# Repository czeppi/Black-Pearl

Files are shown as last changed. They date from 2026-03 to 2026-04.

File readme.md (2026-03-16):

# Black Pearl

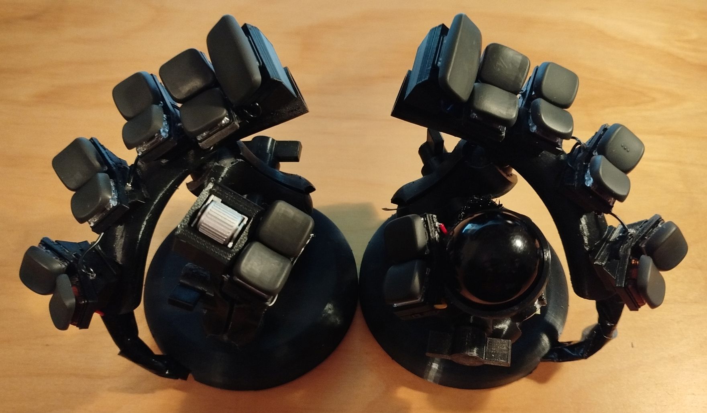
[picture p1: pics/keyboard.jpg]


**An extrem ergonomic keyboard with integrated trackball and roller encoder**

# Quick links

- [build case](case/readme.md)
- [build key caps](caps/readme.md)
- [firmware](firmware/readme.md)

# Features

- min. necessary finger movement
- using QWERTY/QWERTZ
- max. ergonomic
- only 22 keys
- integrated trackball + roller encoder
- hot-swapable
- easy to adjust
- slightly modified KLP key caps
- own firmware (based on Adafruit Circuit Python)
- diodeless
- using Raspberry Pico
- handwired

## using chords for 3rd row

The finger movement should reduced as much as possible.
Every finger was assigned two keys.
Pressing both keys simulates a middle row => a QWERTZ layout is possible.

The Index finger gets 3 physical keys, which can simulate 6 virtual keys.

With the terrific KLP keycaps it is much easier to press both keys blind.

# BOM (Bill of Material)

- 2 raspberry pi Pico (I'm using the Pico 2W, but the Pico 1 should also work)
- 1 PMW3389 trackball sensor
- 3 trackball bearings (s. https://kbd.news/Trackball-bearing-comparison-1757.html, I'm using BTUs of steel)
- 1 EVQWGD001 roller sensor (no longer available, so https://github.com/Taro-Hayashi/THQWGD001 could be a replacement perhaps)
- 2 100mm metal disc (2mm thickness - or more) for the feet
- 22 kailh hot swap sockets
- 22 kailh Choc V1 keys
- lots of 2mm flat hat screws
- lots of 2.5mm flat hat screws
- lots of 3mm 
- lots of heat inserter sets
- lots of cables (I'm using AWG 26 with solid core, but this is a matter of personal preference)

# A look inside

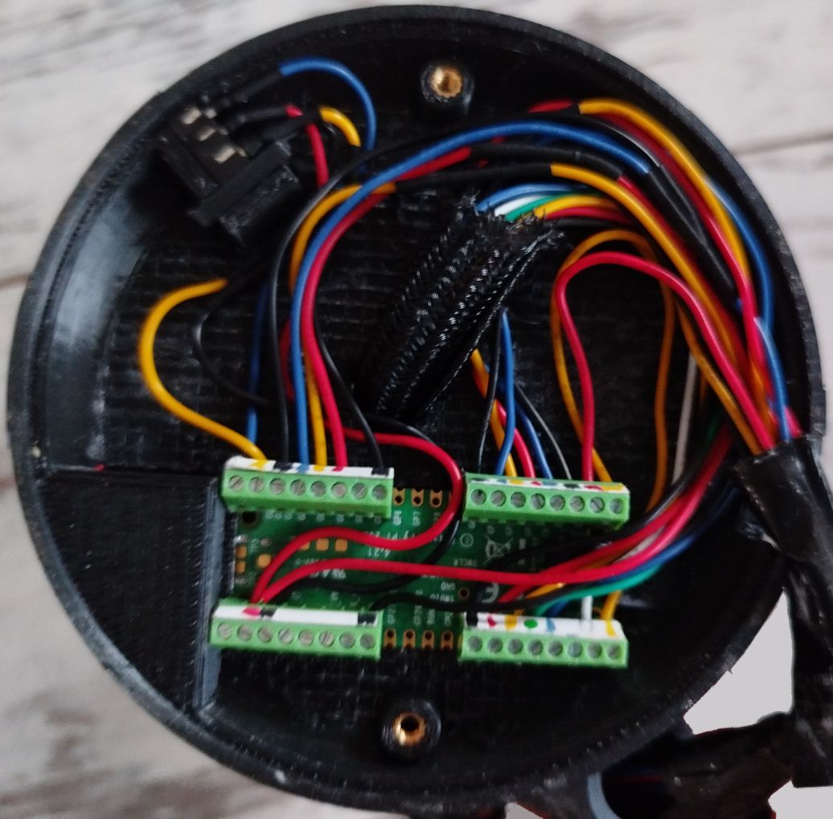
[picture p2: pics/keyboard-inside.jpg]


# Why yet another keyboard?

I'm using a piantor keyboard since over a year and I'm quite happy with it.
The main issue is the lack of a track ball, so I switch beetween keyboard and mouse permantly.
A 2nd disadvantage are the thumb-clusters, which are not very ergonomic.

I'm print the case of a charibdis keyboard, but the distances between the keys are too far for me.

# Some notes to the name

The name relationship to the ship in "Pirates of the Caribbean" is no coincidence.
Cause both has some attributes in common:
- black (that much is certain - with the words of captain Sparrow)
- extraordinary
- fast (hopefully)

...and, every switch pair holder has some similarities to a historical ship

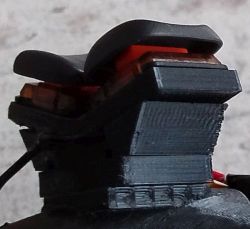
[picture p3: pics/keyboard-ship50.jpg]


# Related keyboards

- Charybdis (a famous keyboard with trackball)
- Dactyl Manuform Skeleton (has a similar exotic design)
- Gull + Heron from Sneftel
- Proto2 + Heavily Modified Gigi (using chords for 3rd row too)

# Licence

- case: CC-BY-SA
- keycaps: CC-BY-SA
- firmware: GPL V3

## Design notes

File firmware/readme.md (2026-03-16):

# Firmware

## Why an own firmware

It is very difficult to simulate a 3rd row with the existing keyboard firmwares like QMK or KMK.
Since I am a professional software developer, I decided to write my own. 
I thought that this should be a small piece of work, cause only a subset of the typically firmware is needed (no matrix for example) - that was an error!
All in all it take over three weeks of work.

## Install

### download circuitpython

you can use a pico or a pico2

pico: https://circuitpython.org/board/raspberry_pi_pico_w/
=> adafruit-circuitpython-raspberry_pi_pico_w-en_US-9.2.9.uf2

pico2: https://circuitpython.org/board/raspberry_pi_pico2_w/ 
=> adafruit-circuitpython-raspberry_pi_pico2_w-en_US-9.2.9.uf2

### install circuitpython

- connect Pico to USB while Sel-button is pressed => new drive appears
- drag&drop utf2 file to that drive => a new drive appears

### download library bundle

https://circuitpython.org/libraries => adafruit-circuitpython-bundle-9.x-mpy-20250911.zip

### install library bundle

- copy folders adafruit_bus_device + adafruit_hid
- from adafruit-circuitpython-bundle-9.x-mpy-20250911.zip/adafruit-circuitpython-bundle-9.x-mpy-20250911/lib
- to   [CIRCUIT-Python-drive]:/lib

### copy files to left half (connected with computer)

copy this files from this directory to [CIRCUIT-Python-drive]:/

- mainleft.py -> code.py
- base.py
- button.py
- kbdlayoutdata.py
- keyboardcreator.py
- keyboardhalf.py
- keysdata.py
- macrosdata
- reactions.py
- uart.py
- virtualkeyboard.py

### copy files to right half (only connected with left half)

copy this files from this directory to [CIRCUIT-Python-drive]:/

- mainright.py -> code.py
- base.py
- button.py
- kbdlayoutdata.py
- keyboardhalf.py
- keysdata.py
- pmw3389
- uart.py

## Connection info of the PMW3389

### Pins of the PMW3389

| board | | color  | description |
|---|----|---|---|
| RST | RS | brown  | Reset |
| GND | GD | red | Ground |
| MT | MT | orange | Motion (active low interrupt line) |
| SS | SS | yellow | Slave Select / Chip Select |
| SCK | SC | green  | SPI Clock |
| MOSI  | MO | blue | |
| MISO  | MI | purple | |
| VIN | VI | gray | Voltage in up to +5.5V |

### Connection to the Pico

| | | |
|---|---|---|
| SPI0_SCK  | Pin 6 | # SPI0_SCK |
| SPI0_MOSI | Pin 7 | # SPI0_TX  |
| SPI0_MISO | Pin 4 | # SPI0_RX  |
	
| | | |
|---|---|---|
| SPI1_SCK  | Pin 10 | # SPI1_SCK |
| SPI1_MOSI | Pin 11 | # SPI1_TX  |
| SPI1_MISO | Pin 8  | # SPI1_RX  |

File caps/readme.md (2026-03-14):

# Create modified KLP Lame key caps

## Install

### required

- install python (3.12)
- pip install build123d  # 0.10.0

### optional for viewing

- pip install ocp_vscode  # 3.1.2
- install visual studio code  (1.111)
- install OCP CAD Viewer plug in (3.1.2)

the versions in paranthesis or comments are my versions. Newer should work also, but are not tested.

## Start

### with viewing

- open Visual Studio Code
- start one of the main_*.py files

### only creating *.stl files

- start one of the main_*.py files

## Results

- the STL file should be shown in the OCP Viewer
- the STL file should be stored in the caps/#output directory

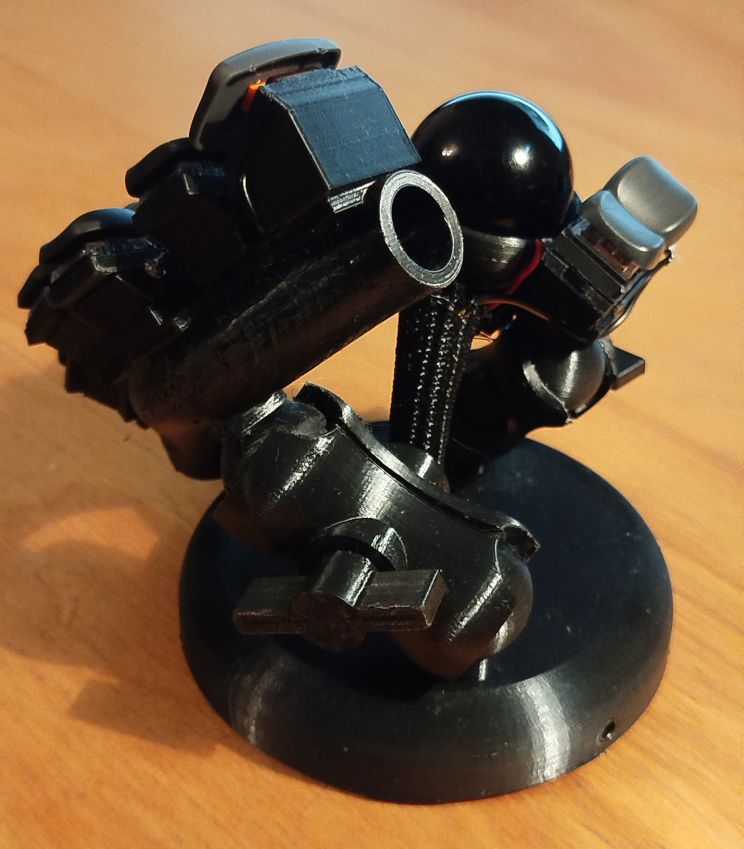
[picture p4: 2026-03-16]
pics/keyboard-right-04.jpg

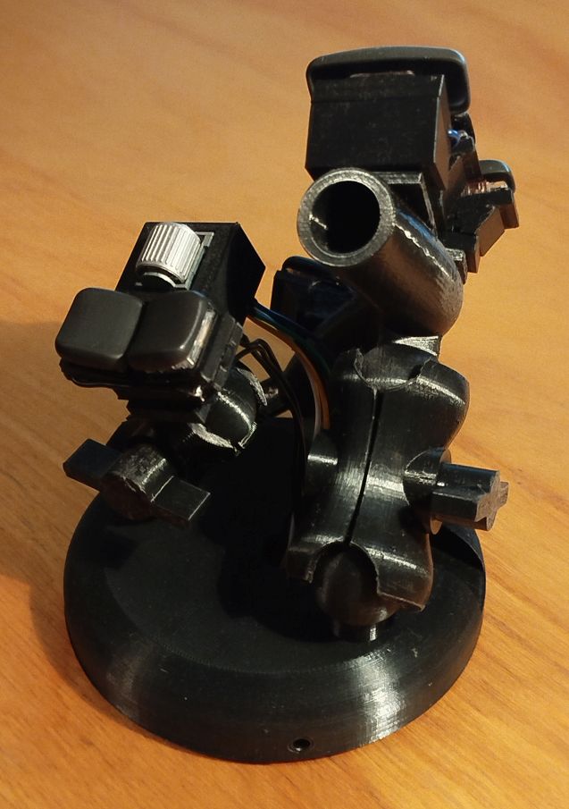
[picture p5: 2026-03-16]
pics/keyboard-left-05.jpg

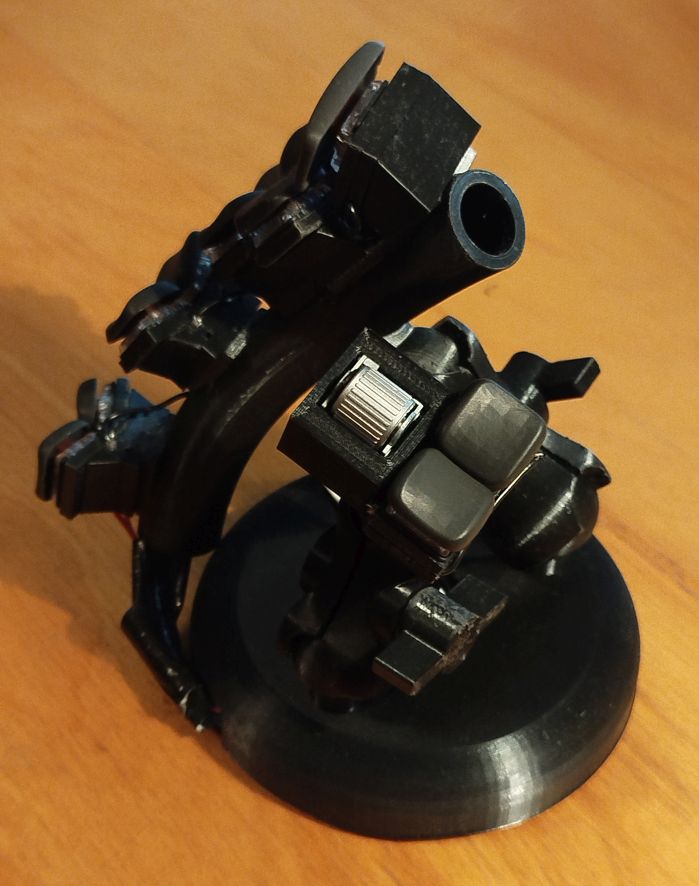
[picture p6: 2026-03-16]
pics/keyboard-left-03.jpg

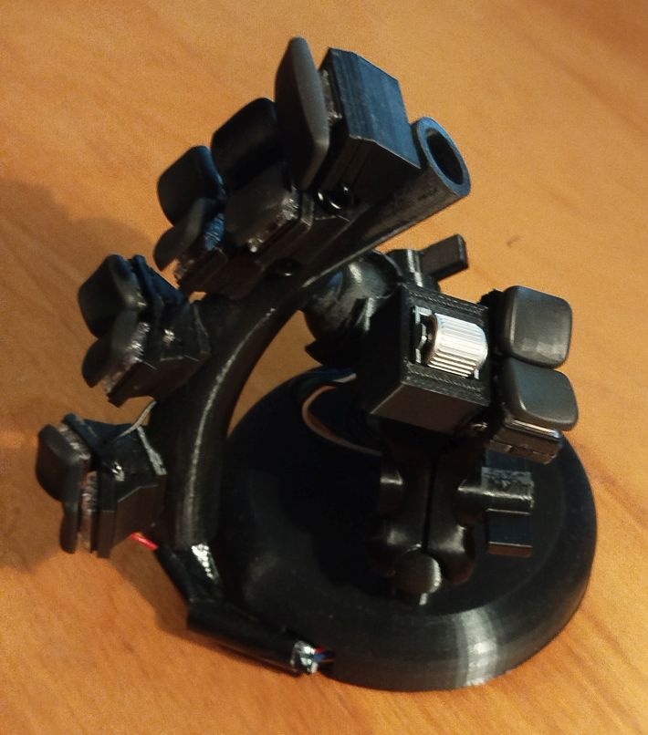
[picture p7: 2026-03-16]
pics/keyboard-left-02.jpg

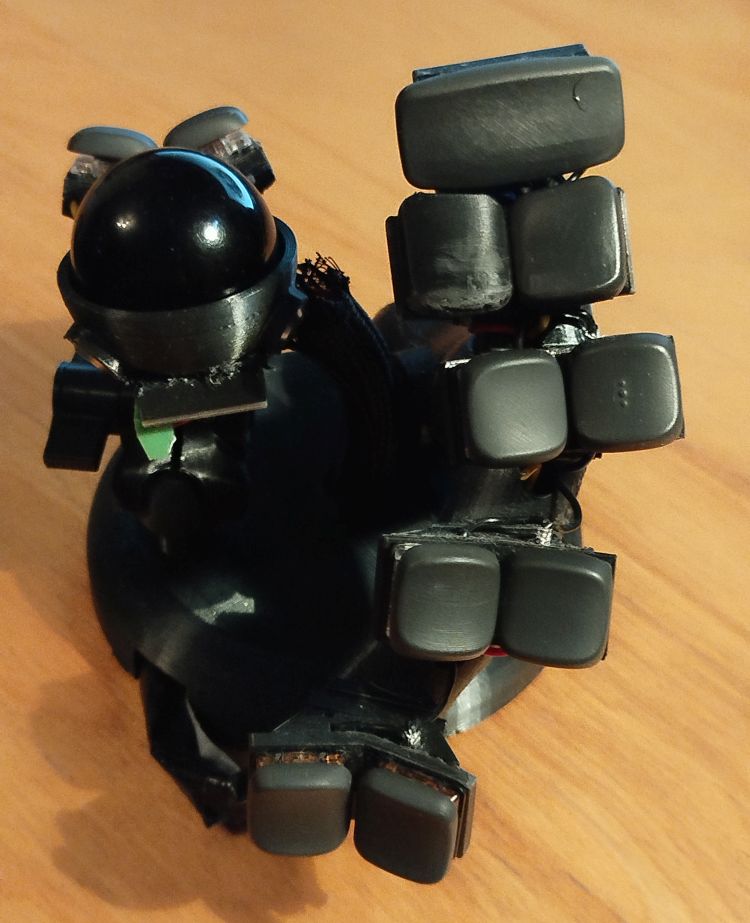
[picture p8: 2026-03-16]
pics/keyboard-right-03.jpg

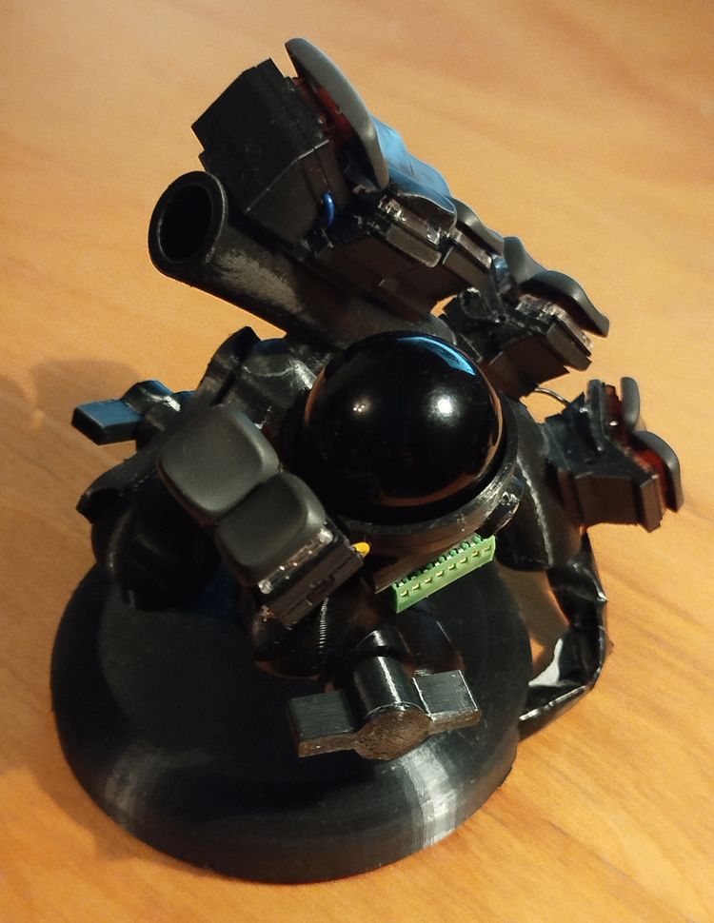
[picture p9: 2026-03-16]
pics/keyboard-right-01.jpg

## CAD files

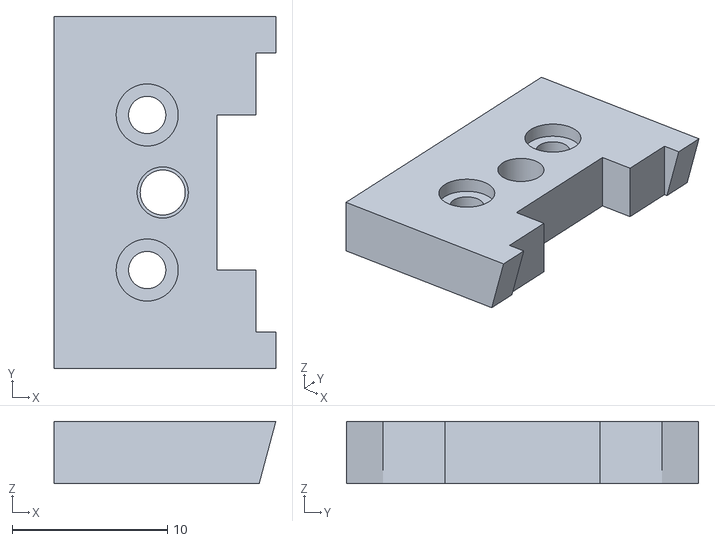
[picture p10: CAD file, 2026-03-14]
stl/case/thumb-switch-holder-right-foot.stl
14.3 x 22.7 x 4.00

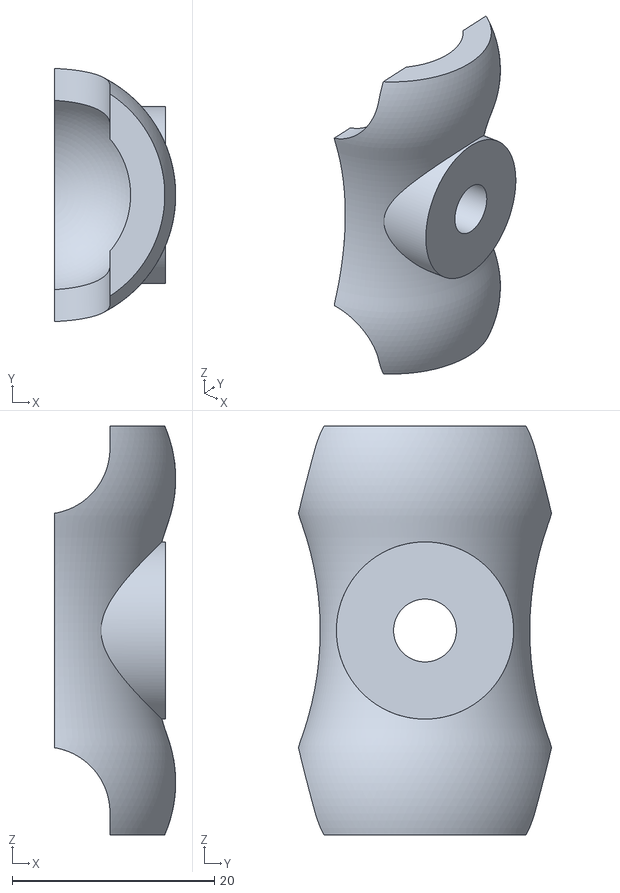
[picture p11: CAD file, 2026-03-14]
stl/case/thumb-double-ball-holder2.stl
12.0 x 25.0 x 40.4

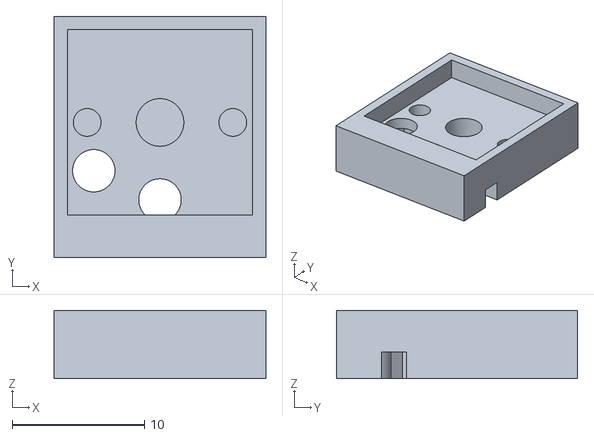
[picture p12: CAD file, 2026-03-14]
stl/case/hot-swap-socket.stl
16.0 x 18.2 x 5.15

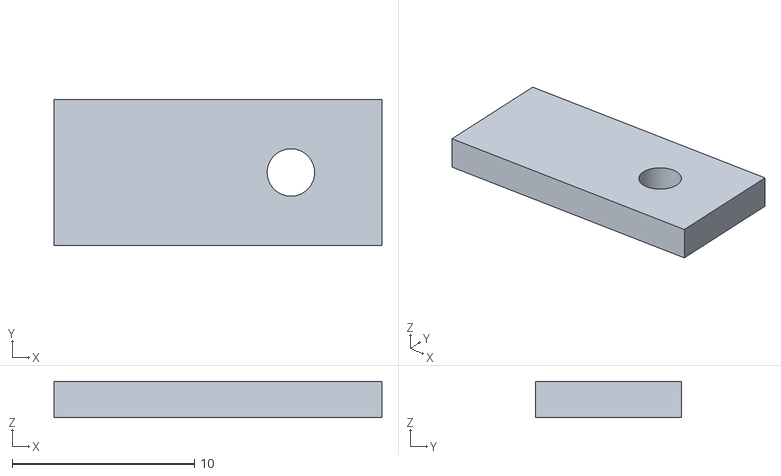
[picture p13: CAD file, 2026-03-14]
stl/case/controller-holder-plate.stl
18.0 x 8.00 x 2.00

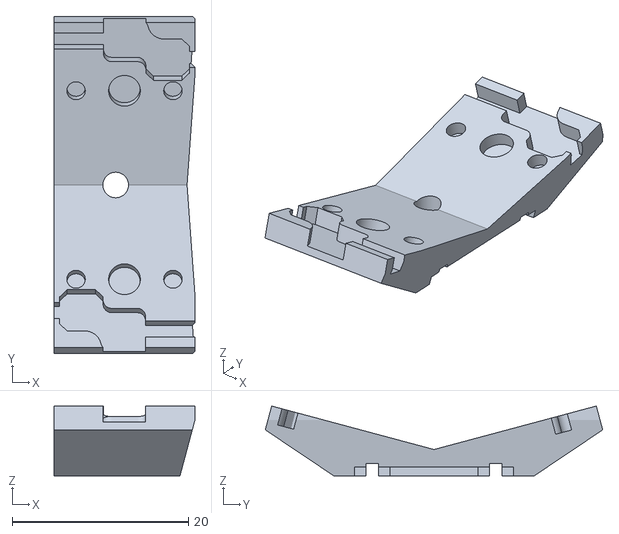
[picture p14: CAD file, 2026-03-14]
stl/case/thumb-switch-holder-right-middle.stl
16.0 x 38.3 x 7.94

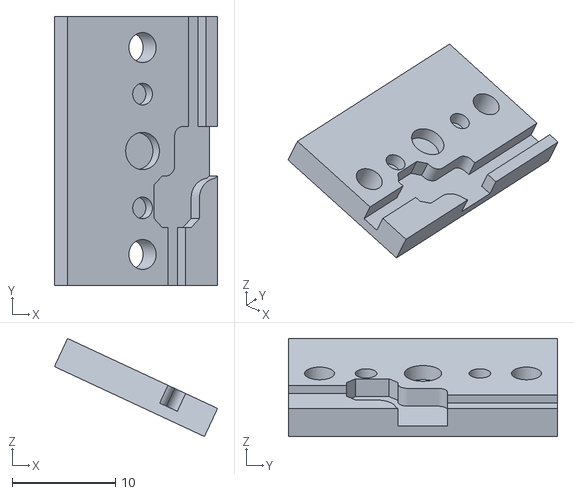
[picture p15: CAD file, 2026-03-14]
stl/case/single-switch-middle.stl
15.8 x 26.0 x 9.48

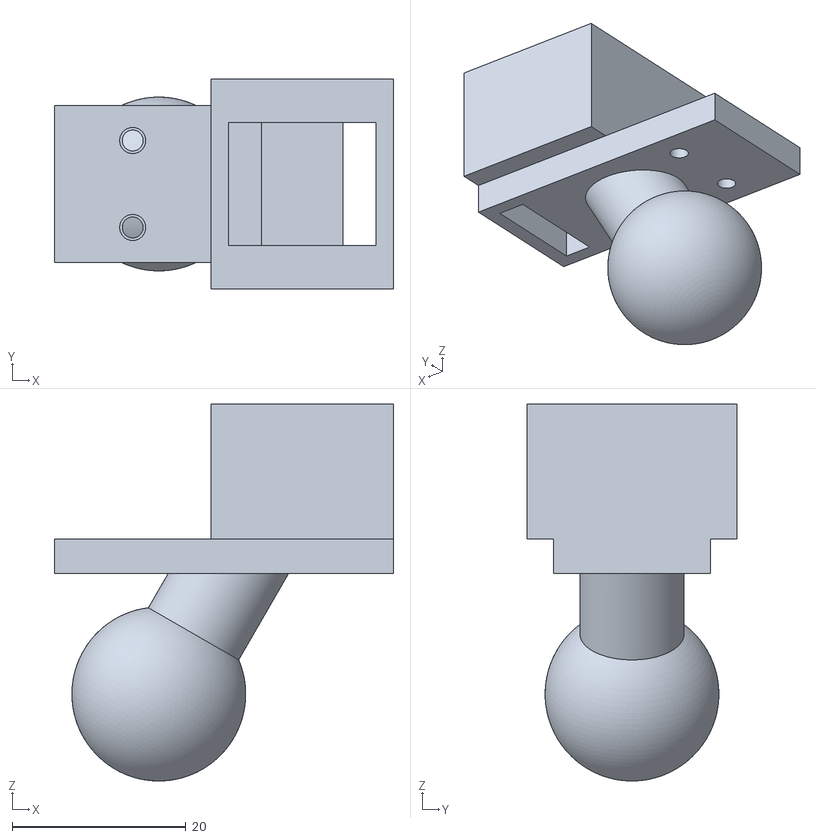
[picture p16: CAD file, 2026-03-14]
stl/case/encoder-holder.stl
39.0 x 24.1 x 43.4

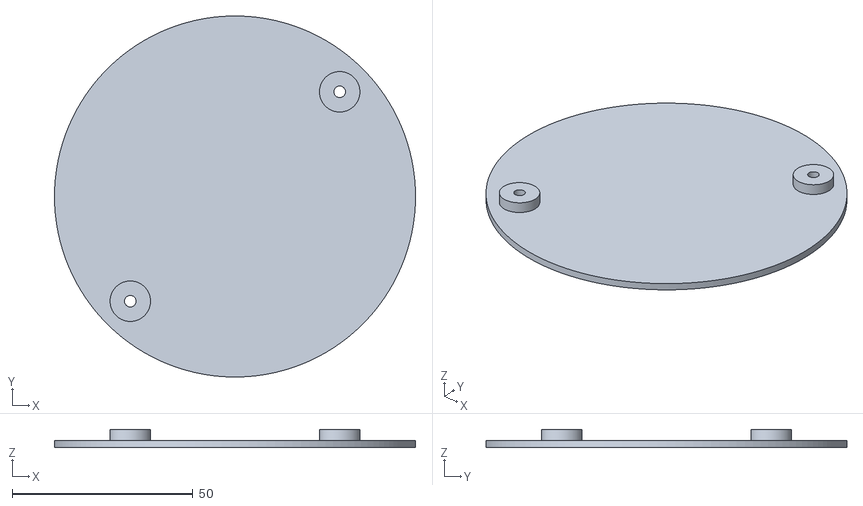
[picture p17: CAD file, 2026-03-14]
stl/case/circle-base-cover.stl
100.0 x 100.0 x 5.10

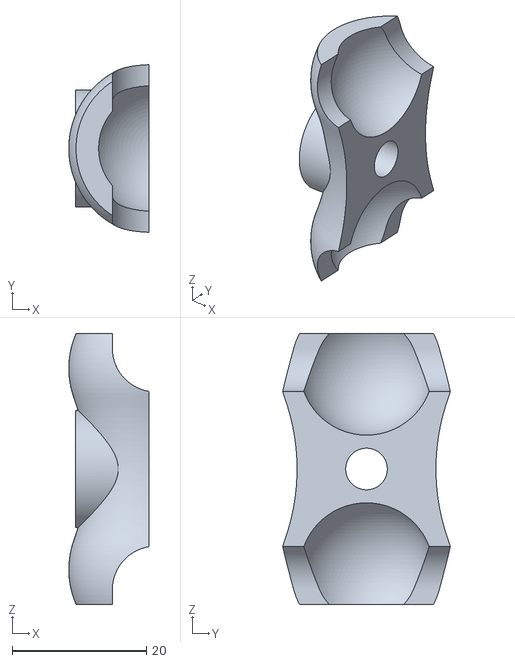
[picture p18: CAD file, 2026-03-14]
stl/case/thumb-double-ball-holder1.stl
12.0 x 25.0 x 40.4

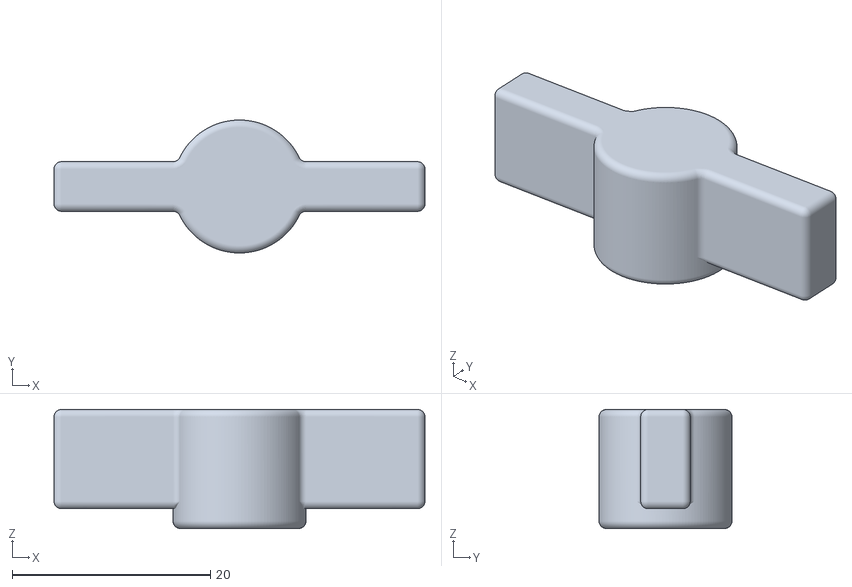
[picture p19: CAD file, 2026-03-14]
stl/case/finger-double-ball-wing.stl
37.4 x 13.4 x 12.0

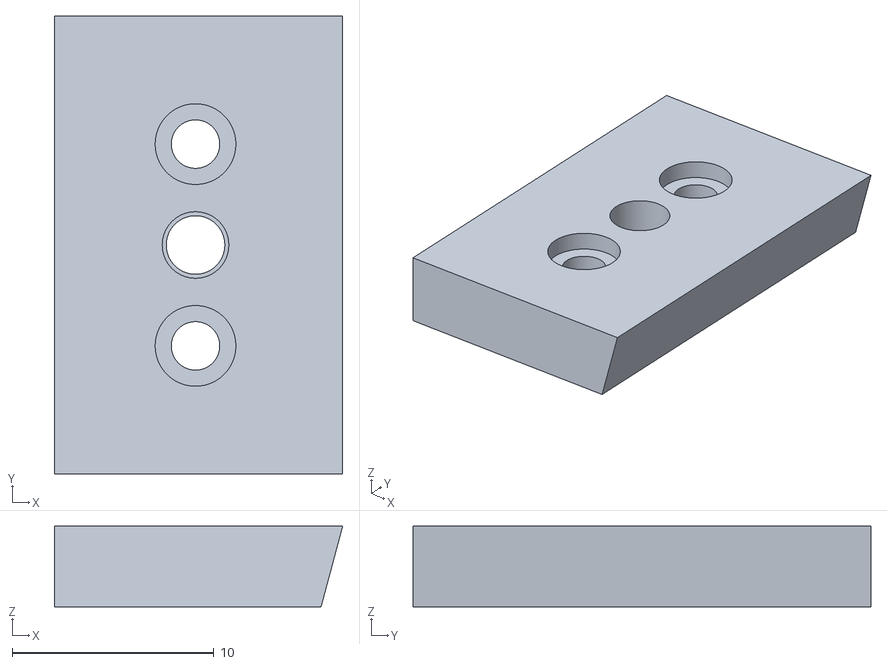
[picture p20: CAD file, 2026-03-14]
stl/case/thumb-switch-holder-left-foot.stl
14.3 x 22.7 x 4.00

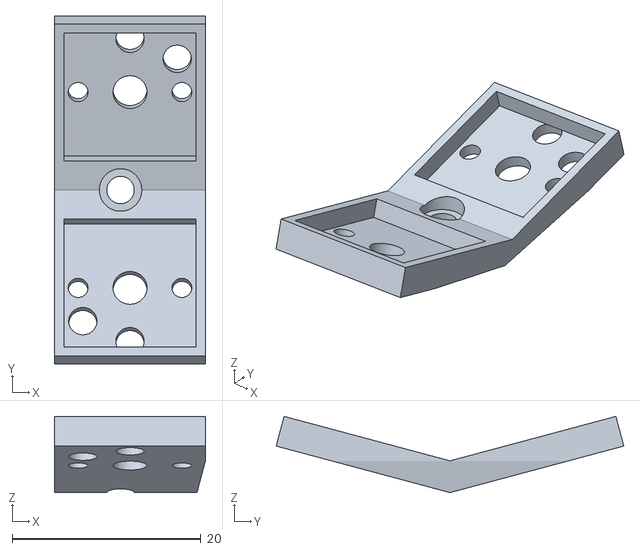
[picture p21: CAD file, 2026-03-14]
stl/case/thumb-switch-holder-left-top.stl
16.0 x 36.8 x 8.08

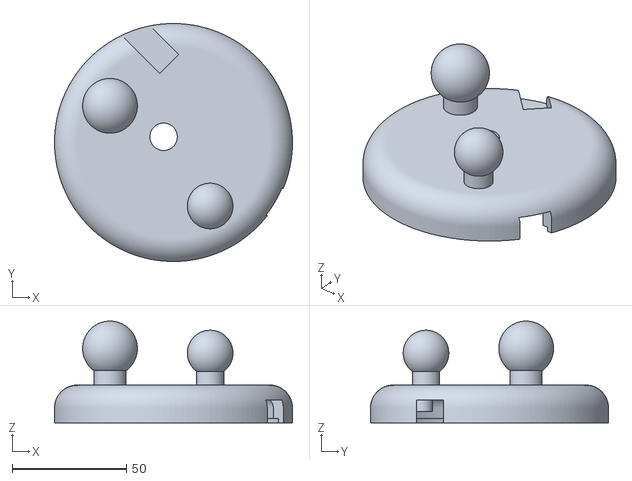
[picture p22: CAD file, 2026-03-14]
stl/case/circle-base-plate.stl
104.2 x 104.2 x 44.6

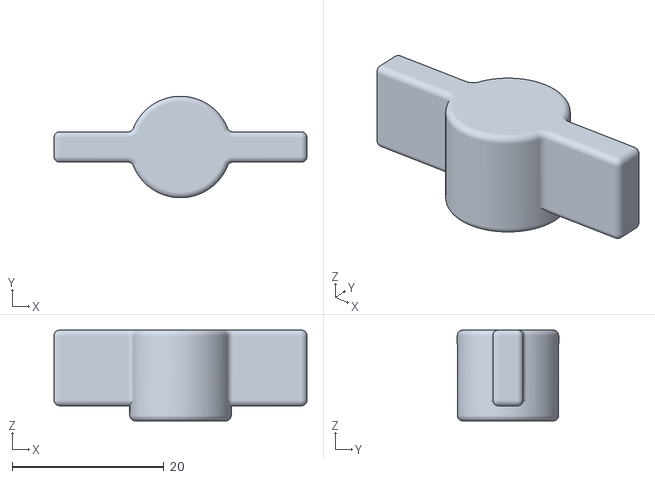
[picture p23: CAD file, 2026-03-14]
stl/case/thumb-double-ball-wing.stl
33.4 x 13.4 x 12.0

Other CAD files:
stl/case/thumb-switch-holder-left-middle.stl
stl/case/single-switch-top.stl
stl/case/trrs_stopper.stl
stl/case/single-switch-foot.stl
stl/case/finger-double-ball-holder1.stl
stl/case/finger-double-ball-holder2.stl
stl/case/skeleton-with-sphere.stl
stl/case/switch-pair-foot.stl
stl/case/switch-pair-middle.stl
stl/case/switch-pair-top.stl
stl/case/trackball-holder.stl

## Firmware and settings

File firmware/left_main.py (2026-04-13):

from __future__ import annotations

from left_keyboardcreator import KeyboardCreator, _KeyReactionData
from left_logging import LogItem, LogItemDumper, EventLogger
from left_reactions import KeyCmdKind, KeyCmd, MouseButtonCmd, MouseWheelCmd, ReactionCmd, \
    MouseButtonCmdKind, LogCmd, ReactionName
from left_rotaryencoderhandler import RotaryEncoderHandler

try:
    from typing import Iterator
except ImportError:
    pass

import time
import board
import usb_hid
from digitalio import DigitalInOut, Direction, Pull
import rotaryio
from adafruit_hid.keycode import Keycode as KC
from adafruit_hid.keyboard import Keyboard
from adafruit_hid.mouse import Mouse

from both_base import PhysicalKeySerial, TimeInMs
from both_button import Button
from both_kbdlayoutdata import LEFT_KEY_GROUPS, VIRTUAL_KEY_ORDER, LAYERS, MODIFIERS
from left_macroslib import read_macros
from both_keyboardhalf import KeyboardHalf, KeyGroup, VKeyPressEvent
from both_keysdata import *
from both_uart import UartBase

# TRRS
#
#   T R1 R2
#   S
#
#   T:  Tip,    VCC, red
#   R1: Ring1,  GND, black
#   R2: Ring2,  RX,  blue
#   S:  Sleeve, TX,  yellow  # not used anymore


LEFT_TX = None  # board.GP0
LEFT_RX = board.GP1

WITH_PRINT = False


def main():
    left_kbd = LeftKeyboardSide()
    left_kbd.init()
    left_kbd.main_loop()


def _print(text: str) -> None:
    if WITH_PRINT:
        print(text)


class LeftUart(UartBase):

    def wait_for_start(self) -> None:
        pass
        # self._uart.read()  # clear buffer

    def read_items(self) -> Iterator[MouseMove | VKeyPressEvent]:
        while self._uart.in_waiting > 0:
            read_1st_bytes = self._uart.read(1)
            if read_1st_bytes == self._MOUSE_BYTES:
                byte1, byte2 = self._uart.read(2)
                _print(f'uart readd mouse: byte1={byte1}, byte2={byte2}')
                dx = byte1 if byte1 < 128 else byte1 - 256
                dy = byte2 if byte2 < 128 else byte2 - 256
                _print(f'uart read mouse: dx={dx}, dy={dy}')
                yield MouseMove(-dx, -dy)
            elif read_1st_bytes == self._KEY_EVENT_BYTES:
                read_bytes = self._uart.read(1)
                byte1 = read_bytes[0]
                signed_value = byte1 if byte1 < 128 else byte1 - 256
                vkey_serial = abs(signed_value)
                pressed = (signed_value > 0)
                _print(f'uart read key event: {vkey_serial} {pressed}')
                yield VKeyPressEvent(vkey_serial=vkey_serial, pressed=pressed)
            else:
                _print(f'uart read unknown byte: {read_1st_bytes}')


class MouseMove:

    def __init__(self, dx: int, dy: int):
        # public
        self.dx = dx
        self.dy = dy


class RollerEncoder:

    def __init__(self, pin1, pin2):
        self._encoder = rotaryio.IncrementalEncoder(pin1, pin2)
        self._last_pos = None

    def update(self) -> int:
        pos = self._encoder.position
        if self._last_pos is None:
            self._last_pos = pos
            return 0

        if pos == self._last_pos:
            return 0

        offset = pos - self._last_pos
        self._last_pos = pos
        return offset


class LeftKeyboardSide:
    _BUTTON_MAP = {
        LEFT_INDEX2_DOWN: board.GP2,  # blue
        LEFT_INDEX_DOWN: board.GP3,  # yellow
        LEFT_INDEX_UP: board.GP4,  # red
        LEFT_INDEX2_UP: board.GP5,  # green
        LEFT_MIDDLE_DOWN: board.GP10,  # blue
        LEFT_MIDDLE_UP: board.GP11,  # yellow
        LEFT_RING_DOWN: board.GP12,  # red
        LEFT_RING_UP: board.GP13,  # blue
        LEFT_PINKY_DOWN: board.GP14,  # red
        LEFT_PINKY_UP: board.GP15,  # yellow
        LEFT_THUMB_DOWN: board.GP21,  # red
        LEFT_THUMB_UP: board.GP20,  # yellow
    }
    _ROTARY_PIN1 = board.GP16
    _ROTARY_PIN2 = board.GP17

    def __init__(self):
        self._uart = LeftUart(tx=LEFT_TX, rx=LEFT_RX)
        self._roller_encoder = RollerEncoder(self._ROTARY_PIN1, self._ROTARY_PIN2)
        self._buttons = [Button(pkey_serial=pkey_serial, gp_pin=gp_pin) for pkey_serial, gp_pin in self._BUTTON_MAP.items()]
        self._kbd_half = KeyboardHalf(key_groups=[KeyGroup(group_data)
                                                  for group_data in LEFT_KEY_GROUPS])
        macros = read_macros()

        creator = KeyboardCreator(virtual_key_order=VIRTUAL_KEY_ORDER,
                                  layers=LAYERS,
                                  modifiers=MODIFIERS,
                                  macros=macros)
        self._virt_keyboard = creator.create()
        self._reaction_map = creator.create_reaction_map()
        self._key_code_map = creator.create_key_code_map()
        self._roller_encoder_handler = RotaryEncoderHandler()

        self._kbd_device = Keyboard(usb_hid.devices)
        self._mouse_device = Mouse(usb_hid.devices)
        self._queue: list[QueueItem] = []
        self._log_items: list[LogItem] = []
        self._event_logger = EventLogger()

    def init(self) -> None:
        _print('init uart...')
        self._uart.wait_for_start()

    def main_loop(self) -> None:
        _print('start main loop')
        i = 0
        while True:
            try:
                if i % 500 == 0:
                    _print(i)
                self._read_devices()

                for queue_item in self._read_queue_items():
                    self._process_queue_item(queue_item)

                time.sleep(0.001)
            except Exception as err:
                _print(f'ERROR : {err}')
                time.sleep(0.5)
            i += 1

    def _read_devices(self) -> None:
        t = time.monotonic() * 1000

        # _print(f'_read_devices: t={t}')
        my_pressed_pkeys = self._get_pressed_pkeys()

        encoder_offset = self._roller_encoder.update()
        if encoder_offset != 0:
            _print(f'encoder_offset={encoder_offset}')

        mouse_dx = mouse_dy = 0
        other_vkey_events: list[VKeyPressEvent] = []
        for uart_item in self._uart.read_items():
            if isinstance(uart_item, MouseMove):
                mouse_move = uart_item
                mouse_dx += mouse_move.dx
                mouse_dy += mouse_move.dy
            elif isinstance(uart_item, VKeyPressEvent):
                vkey_evt = uart_item
                other_vkey_events.append(vkey_evt)

        queue_item = QueueItem(time=t, mouse_move=MouseMove(dx=mouse_dx, dy=mouse_dy),
                               encoder_offset=encoder_offset,
                               my_pressed_pkeys=my_pressed_pkeys,
                               other_vkey_events=other_vkey_events)
        #_print(f'read_devices: {queue_item}')
        self._queue.append(queue_item)

    def _read_queue_items(self) -> Iterator[QueueItem]:
        while len(self._queue) > 0:
            queue_item = self._queue[0]
            self._queue = self._queue[1:]
            yield queue_item

    def _process_queue_item(self, queue_item: QueueItem) -> None:
        #_print(f'_process_queue_item: {queue_item}')
        mouse_dx = queue_item.mouse_move.dx
        mouse_dy = queue_item.mouse_move.dy
        if mouse_dx != 0 or mouse_dy != 0:
            self._mouse_device.move(mouse_dx, mouse_dy)

        if queue_item.encoder_offset != 0:
            _print(f'mouse wheel: {queue_item.encoder_offset}')

        my_vkey_events = list(self._kbd_half.update(time=queue_item.time,
                                                    cur_pressed_pkeys=queue_item.my_pressed_pkeys))
        vkey_events = queue_item.other_vkey_events + my_vkey_events
        t = time.monotonic() * 1000
        vkey_reaction_commands = list(self._virt_keyboard.update(time=t, vkey_events=vkey_events))

        encoder_reaction_commands = list(
            self._roller_encoder_handler.update(time=t,
                                                encoder_offset=queue_item.encoder_offset,
                                                vkey_reaction_commands=vkey_reaction_commands,
                                                mouse_dx=mouse_dx, mouse_dy=mouse_dy)
        )
        reaction_commands = vkey_reaction_commands + encoder_reaction_commands

        self._event_logger.update(t=t, vkey_events=vkey_events, reaction_commands=reaction_commands)

        for reaction_cmd in reaction_commands:
            self._send_reaction_cmd(reaction_cmd)

    def _get_pressed_pkeys(self) -> set[PhysicalKeySerial]:
        return {button.pkey_serial
                for button in self._buttons
                if button.is_pressed()}

    def _send_reaction_cmd(self, reaction_cmd: ReactionCmd) -> None:
        if isinstance(reaction_cmd, KeyCmd):
            cmd_executer = KeyCmdExecuter(self._kbd_device)
            cmd_executer.execute(reaction_cmd)
        elif isinstance(reaction_cmd, MouseButtonCmd):
            mouse_cmd = reaction_cmd
            if mouse_cmd.kind == MouseButtonCmdKind.MOUSE_PRESS:
                _print(f'press mouse button {mouse_cmd.button_no}')
                self._mouse_device.press(mouse_cmd.button_no)
            elif mouse_cmd.kind == MouseButtonCmdKind.MOUSE_RELEASE:
                _print(f'release mouse button {mouse_cmd.button_no}')
                self._mouse_device.release(mouse_cmd.button_no)
        elif isinstance(reaction_cmd, MouseWheelCmd):
            self._mouse_device.move(wheel=reaction_cmd.offset)
        elif isinstance(reaction_cmd, LogCmd):
            self._send_log_key_codes()

    def _send_log_key_codes(self):
        dumper = LogItemDumper(key_code_map=self._key_code_map)
        text = '\n' + '\n'.join(dumper.dump(log_item) for log_item in self._log_items[:-2]) + '\n'

        converter = TextToKeyCodeConverter(reaction_map=self._reaction_map)
        key_commands = list(converter.convert_text(text))

        cmd_executer = KeyCmdExecuter(self._kbd_device)
        for key_cmd in key_commands:
            cmd_executer.execute(key_cmd)


class QueueItem:

    def __init__(self, time: TimeInMs, mouse_move: MouseMove, encoder_offset: int,
                 my_pressed_pkeys: set[PhysicalKeySerial], other_vkey_events: list[VKeyPressEvent]):
        # public
        self.time = time
        self.mouse_move = mouse_move
        self.encoder_offset = encoder_offset
        self.my_pressed_pkeys = my_pressed_pkeys
        self.other_vkey_events = other_vkey_events

    def __str__(self) -> str:
        return f'QueueItem({self.time}, mouse=({self.mouse_move.dx, self.mouse_move.dy}), my-pkeys=({self.my_pressed_pkeys})), other-vkey={self.other_vkey_events})'


class TextToKeyCodeConverter:

    def __init__(self, reaction_map: dict[ReactionName, _KeyReactionData]):
        self._reaction_map = reaction_map

    def convert_text(self, text: str) -> Iterator[KeyCmd]:
        for char in text:
            yield from self._convert_char(char)

    def _convert_char(self, char: str) -> Iterator[KeyCmd]:
        if char == '\n':
            yield KeyCmd(kind=KeyCmdKind.KEY_SEND, key_code=KC.ENTER)
            return

        reaction_data = self._reaction_map.get(char)
        if reaction_data is None:
            return

        if reaction_data.with_shift:
            yield KeyCmd(kind=KeyCmdKind.KEY_PRESS, key_code=KC.LEFT_SHIFT)

        if reaction_data.with_alt:
            yield KeyCmd(kind=KeyCmdKind.KEY_PRESS, key_code=KC.RIGHT_ALT)

        yield KeyCmd(kind=KeyCmdKind.KEY_SEND, key_code=reaction_data.key_code)

        if reaction_data.with_alt:
            yield KeyCmd(kind=KeyCmdKind.KEY_RELEASE, key_code=KC.RIGHT_ALT)

        if reaction_data.with_shift:
            yield KeyCmd(kind=KeyCmdKind.KEY_RELEASE, key_code=KC.LEFT_SHIFT)


class KeyCmdExecuter:

    def __init__(self, kbd_device: Keyboard):
        self._kbd_device = kbd_device

    def execute(self, key_cmd: KeyCmd) -> None:
        if key_cmd.kind == KeyCmdKind.KEY_PRESS:
            _print(f'press key {key_cmd.key_code}...')
            self._kbd_device.press(key_cmd.key_code)
        elif key_cmd.kind == KeyCmdKind.KEY_RELEASE:
            _print(f'release key {key_cmd.key_code}...')
            self._kbd_device.release(key_cmd.key_code)
        elif key_cmd.kind == KeyCmdKind.KEY_SEND:
            _print(f'send key {key_cmd.key_code}...')
            self._kbd_device.send(key_cmd.key_code)


if __name__ == '__main__':
    main()

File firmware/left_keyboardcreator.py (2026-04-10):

from both_base import KeyCode, VirtualKeySerial, LayerID
from both_keysdata import NO_KEY
from left_virtualkeyboard import SimpleKey, ModKey, LayerKey, VirtualKeyboard, Layer
from left_reactions import KeyCmdKind, KeyCmd, OneKeyReactions, MouseButtonCmd, MouseWheelCmd, MouseButtonCmdKind, \
    LogCmd, ReactionName

try:
    from typing import Callable, Iterator, Optional
except ImportError:
    pass

from adafruit_hid.keycode import Keycode as KC
from adafruit_hid.mouse import Mouse

MacroName = str  # p.e. 'M3'
MacroDescription = str
ModKeyName = str  # p.e. 'LCtrl'

KEYCODES_DATA = [
    # function row on std keyboard
    [KC.ESCAPE, 'Esc', '', 'Esc', ''],
    [KC.F1, 'F1', '', 'F1', ''],
    [KC.F2, 'F2', '', 'F2', ''],
    [KC.F3, 'F3', '', 'F3', ''],
    [KC.F4, 'F4', '', 'F4', ''],
    [KC.F5, 'F5', '', 'F5', ''],
    [KC.F6, 'F6', '', 'F6', ''],
    [KC.F7, 'F7', '', 'F7', ''],
    [KC.F8, 'F8', '', 'F8', ''],
    [KC.F9, 'F9', '', 'F9', ''],
    [KC.F10, 'F10', '', 'F10', ''],
    [KC.F11, 'F11', '', 'F11', ''],
    [KC.F12, 'F12', '', 'F12', ''],

    # row 1 on std keyboard
    [KC.GRAVE_ACCENT, '`', '~', '^', '°'],
    [KC.ONE, '1', '!', '1', '!'],
    [KC.TWO, '2', '@', '2', '"'],
    [KC.THREE, '3', '#', '3', '§'],
    [KC.FOUR, '4', '$', '4', '$'],
    [KC.FIVE, '5', '%', '5', '%'],
    [KC.SIX, '6', '^', '6', '&'],
    [KC.SEVEN, '7', '&', '7', '/', '{'],
    [KC.EIGHT, '8', '*', '8', '(', '['],
    [KC.NINE, '9', '(', '9', ')', ']'],
    [KC.ZERO, '0', ')', '0', '=', '}'],
    [KC.MINUS, '-', '_', 'ß', '?', '\\'],
    [KC.EQUALS, '=', '+', '´', '`'],
    [KC.BACKSPACE, 'Backspace', '', 'Backspace', ''],

    # row 2 on std keyboard
    [KC.TAB, 'Tab', 'BackTab', 'Tab', 'BackTab'],
    # q ... p
    [KC.LEFT_BRACKET, '[', '{', 'ü', 'Ü'],
    [KC.RIGHT_BRACKET, ']', '}', '+', '*', '~'],
    [KC.ENTER, 'Enter', '', 'Enter', ''],

    # row 3 on std keyboard
    [KC.CAPS_LOCK, 'CapsLock', '', 'CapsLock', ''],
    # a ... l
    [KC.SEMICOLON, ';', ':', 'ö', 'Ö'],
    [KC.QUOTE, "'", '"', 'ä', 'Ä'],
    [KC.POUND, '#', '~', '#', "'"],

    # row 4 on std keyboard
    [KC.LEFT_SHIFT, 'LShift', '', 'LShift', ''],
    [KC.KEYPAD_BACKSLASH, '\\', '|', '<', '>', '|'],
    # y ... m
    [KC.COMMA, ',', '<', ',', ';'],
    [KC.PERIOD, '.', '>', '.', ':'],
    [KC.FORWARD_SLASH, '/', '?', '-', '_'],
    [KC.RIGHT_SHIFT, 'RShift', '', 'RShift', ''],

    # row 5 on std keyboard
    [KC.LEFT_CONTROL, 'LCtrl', '', 'LCtrl', ''],
    [KC.LEFT_GUI, 'LGui', '', 'LGui', ''],
    [KC.LEFT_ALT, 'LAlt', '', 'LAlt', ''],
    [KC.SPACE, 'Space', '', 'Space', ''],
    [KC.RIGHT_ALT, 'RAlt', '', 'RAlt', ''],
    [KC.RIGHT_GUI, 'RGui', '', 'RGui', ''],
    [KC.APPLICATION, 'Menu', '', 'Menu', ''],

    # cursor row 1 on std keyboard
    [KC.INSERT, 'Insert', '', 'Insert', ''],
    [KC.HOME, 'Home', '', 'Home', ''],
    [KC.PAGE_UP, 'PageUp', '', 'PageUp', ''],

    # cursor row 2 on std keyboard
    [KC.DELETE, 'Del', '', 'Del', ''],
    [KC.END, 'End', '', 'End', ''],
    [KC.PAGE_DOWN, 'PageDown', '', 'PageDown', ''],

    # cursor row 3 on std keyboard
    [KC.UP_ARROW, 'Up', '', 'Up', ''],

    # cursor row 4 on std keyboard
    [KC.LEFT_ARROW, 'Left', '', 'Left', ''],
    [KC.DOWN_ARROW, 'Down', '', 'Down', ''],
    [KC.RIGHT_ARROW, 'Right', '', 'Right', ''],

    # keypad row 1 on std keyboard
    [KC.KEYPAD_NUMLOCK, 'KpNumLock', '', 'KpNumLock', ''],
    [KC.KEYPAD_FORWARD_SLASH, 'Kp/', '', 'Kp/', ''],
    [KC.KEYPAD_ASTERISK, 'Kp*', '', 'Kp*', ''],
    [KC.KEYPAD_MINUS, 'Kp', '', 'Kp', ''],

    # keypad row 2 on std keyboard
    [KC.KEYPAD_SEVEN, 'Kp7', '', 'Kp7', ''],
    [KC.KEYPAD_EIGHT, 'Kp8', '', 'Kp8', ''],
    [KC.KEYPAD_NINE, 'Kp9', '', 'Kp9', ''],
    [KC.KEYPAD_PLUS, 'Kp+', '', 'Kp+', ''],

    # keypad row 3 on std keyboard
    [KC.KEYPAD_FOUR, 'Kp4', '', 'Kp4', ''],
    [KC.KEYPAD_FIVE, 'Kp5', '', 'Kp5', ''],
    [KC.KEYPAD_SIX, 'Kp6', '', 'Kp6', ''],

    # keypad row 4 on std keyboard
    [KC.KEYPAD_ONE, 'Kp1', '', 'Kp1', ''],
    [KC.KEYPAD_TWO, 'Kp2', '', 'Kp2', ''],
    [KC.KEYPAD_THREE, 'Kp3', '', 'Kp3', ''],
    [KC.KEYPAD_ENTER, 'KpEnter', '', 'KpEnter', ''],

    # keypad row 5 on std keyboard
    [KC.KEYPAD_ZERO, 'Kp0', 'KpInsert', 'Kp0', 'KpInsert'],
    [KC.KEYPAD_PERIOD, 'Kp.', 'KpDel', '', 'KpDel'],
]


class _KeyReactionData:

    def __init__(self, key_code: KeyCode, with_shift: bool, with_alt: bool = False, name: str = '???'):
        self.key_code = key_code
        self.with_shift = with_shift
        self.with_alt = with_alt
        self.name = name
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

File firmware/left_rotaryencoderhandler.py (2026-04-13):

from __future__ import annotations

try:
    from typing import Iterator
except ImportError:
    pass

from adafruit_hid.keycode import Keycode as KC
from both_base import TimeInMs, KeyCode
from left_reactions import ReactionCmd, MouseWheelCmd, KeyCmd, KeyCmdKind


KeyCodeCombination = tuple  # tuple[KeyCode, ...]


class RotaryEncoderHandler:

    def __init__(self):
        self._key_code_recorder = _KeyCodeRecorder()
        self._reverse_combi_map = dict(ReverseKeyCodeCreator.iter_reverse_key_code_combinations())

    def update(self, time: TimeInMs, encoder_offset: int, mouse_dx: int, mouse_dy: int,
               vkey_reaction_commands: list[ReactionCmd]) -> Iterator[ReactionCmd]:
        self._key_code_recorder.update(time=time, mouse_move=(mouse_dx != 0 or mouse_dy != 0),
                                       vkey_reaction_commands=vkey_reaction_commands)

        if encoder_offset == 0:
            return

        key_code_combi = self._key_code_recorder.key_code_combination
        if len(key_code_combi) == 0:
            yield MouseWheelCmd(offset=encoder_offset)
        else:
            #print(f'key_code_combi={key_code_combi}, encoder_offset={encoder_offset}')

            if encoder_offset < 0:
                key_code_combi = self._reverse_combi_map.get(key_code_combi, tuple())
            commands = list(self._iter_key_commands_from_combi(key_code_combi))

            for _ in range(abs(encoder_offset)):
                yield from commands

    @staticmethod
    def _iter_key_commands_from_combi(key_code_combi: KeyCodeCombination) -> Iterator[KeyCmd]:
        for key_code in key_code_combi:
            yield KeyCmd(kind=KeyCmdKind.KEY_PRESS, key_code=key_code)
        for key_code in reversed(key_code_combi):
            yield KeyCmd(kind=KeyCmdKind.KEY_RELEASE, key_code=key_code)


class _KeyCodeRecorder:
    _MAX_TIME_BETWEEN_KEY_COMMANDS = 2000  # in ms

    def __init__(self):
        self._last_time: TimeInMs = -1
        self._key_code_sequence: list[KeyCode] = []
        self._num_pressed_key_codes = 0

    def clear(self) -> None:
        self._key_code_sequence.clear()
        self._num_pressed_key_codes = 0

    def update(self, time: TimeInMs, mouse_move: bool,
               vkey_reaction_commands: list[ReactionCmd]) -> None:
        if mouse_move: # or time - self._last_time > self._MAX_TIME_BETWEEN_KEY_COMMANDS:
            self.clear()

        if len(vkey_reaction_commands) > 0 and self._num_pressed_key_codes == 0:
            self.clear()

        for reaction_cmd in vkey_reaction_commands:
            if isinstance(reaction_cmd, KeyCmd):
                self._update_key_cmd(key_cmd=reaction_cmd)
            else:
                self.clear()

    def _update_key_cmd(self, key_cmd: KeyCmd) -> None:
        if key_cmd.kind == KeyCmdKind.KEY_PRESS:
            self._key_code_sequence.append(key_cmd.key_code)
            self._num_pressed_key_codes += 1
        elif key_cmd.kind == KeyCmdKind.KEY_RELEASE:
            self._num_pressed_key_codes -= 1
        elif key_cmd.kind == KeyCmdKind.KEY_SEND:
            self._key_code_sequence.append(key_cmd.key_code)

    @property
    def key_code_combination(self) -> KeyCodeCombination:
        return tuple(self._key_code_sequence)


class ReverseKeyCodeCreator:

    @classmethod
    def iter_reverse_key_code_combinations(cls) -> Iterator[tuple[KeyCodeCombination, KeyCodeCombination]]:
        codes_with_poss_shift: list[KeyCode] = list(cls._iter_normal_char_key_codes_with_poss_shift())
        codes_without_poss_shift: list[KeyCode] = list(cls._iter_normal_char_key_codes_with_poss_shift())

        for key_code in codes_with_poss_shift + codes_without_poss_shift:
            yield (key_code,), (KC.BACKSPACE,)

        for key_code in codes_with_poss_shift:
            yield (KC.SHIFT, key_code), (KC.BACKSPACE,)

        for key_code1, key_code2 in cls._iter_symmetric_key_code_pairs():
            yield (key_code1,), (key_code2,)
            yield (key_code2,), (key_code1,)

        for key_combi1, key_combi2 in cls._iter_symmetric_key_combination_pairs():
            yield key_combi1, key_combi2
            yield key_combi2, key_combi1

    @staticmethod
    def _iter_normal_char_key_codes_with_poss_shift() -> Iterator[KeyCode]:
        yield from range(KC.A, KC.Z + 1)
        yield from [KC.ZERO, KC.ONE, KC.TWO, KC.THREE, KC.FOUR, KC.FIVE, KC.SIX, KC.SEVEN, KC.EIGHT, KC.NINE]
        yield from [KC.MINUS, KC.EQUALS, KC.LEFT_BRACKET, KC.RIGHT_BRACKET, KC.SEMICOLON, KC.QUOTE, KC.POUND, KC.COMMA,
                    KC.PERIOD, KC.FORWARD_SLASH, KC.KEYPAD_BACKSLASH]

    @staticmethod
    def _iter_normal_char_key_codes_without_poss_shift() -> Iterator[KeyCode]:
        yield from [KC.KEYPAD_ZERO, KC.KEYPAD_ONE, KC.KEYPAD_TWO, KC.KEYPAD_THREE, KC.KEYPAD_FOUR,
                    KC.KEYPAD_FIVE, KC.KEYPAD_SIX, KC.KEYPAD_SEVEN, KC.KEYPAD_EIGHT, KC.KEYPAD_NINE]
        yield from [KC.KEYPAD_FORWARD_SLASH, KC.KEYPAD_ASTERISK, KC.KEYPAD_MINUS, KC.KEYPAD_PERIOD]

    @staticmethod
    def _iter_symmetric_key_code_pairs() -> Iterator[tuple[KeyCode, KeyCode]]:
        yield KC.LEFT_ARROW, KC.RIGHT_ARROW
        yield KC.DOWN_ARROW, KC.UP_ARROW
        yield KC.PAGE_DOWN, KC.PAGE_UP

    @staticmethod
    def _iter_symmetric_key_combination_pairs() -> Iterator[tuple[KeyCodeCombination, KeyCodeCombination]]:
        yield (KC.LEFT_ALT, KC.DOWN_ARROW), (KC.LEFT_ALT, KC.UP_ARROW)
        yield (KC.LEFT_CONTROL, KC.DOWN_ARROW), (KC.LEFT_CONTROL, KC.UP_ARROW)

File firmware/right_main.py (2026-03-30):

import time

import right_pmw3389
import board
from digitalio import DigitalInOut, Direction

from both_base import PhysicalKeySerial
from both_button import Button
from both_kbdlayoutdata import RIGHT_KEY_GROUPS
from both_keyboardhalf import KeyboardHalf, KeyGroup, VKeyPressEvent
from both_keysdata import *
from both_uart import UartBase

# TRRS
#
#   T R1 R2
#   S
#
#   T:  Tip,    VCC, red
#   R1: Ring1,  GND, black
#   R2: Ring2,  RX,  blue
#   S:  Sleeve, TX,  yellow

RIGHT_TX = board.GP4  # board.GP0
RIGHT_RX = None       # board.GP1


def main():
    right_kbd = RightKeyboardSide()
    right_kbd.init()
    right_kbd.main_loop()


class RightUart(UartBase):

    def wait_for_start(self) -> None:
        #self._uart.read()  # clear buffer
        time.sleep(1.0)  # give left side some time for init

    def write_mouse_move(self, dx: int, dy: int) -> None:
        print(f'write_mouse_move(dx: {type(dx)} = {dx}, dy: {type(dy)} = {dy}')
        x_bytes = dx.to_bytes(1, 'big', signed=True)
        y_bytes = dy.to_bytes(1, 'big', signed=True)
        data = self._MOUSE_BYTES + x_bytes + y_bytes
        print(f'uart write {data}...')
        self._uart.write(data)

    def write_vkey_events(self, vkey_events: list[VKeyPressEvent]) -> None:
        for vkey_evt in vkey_events:
            if vkey_evt.pressed:
                signed_serial = vkey_evt.vkey_serial
            else:
                signed_serial = -vkey_evt.vkey_serial

            print(f'uart signed_serial={signed_serial}')
            vkey_bytes = signed_serial.to_bytes(1, 'big', signed=True)
            data = self._KEY_EVENT_BYTES + vkey_bytes

            print(f'uart write {data}...')
            self._uart.write(data)


class TrackballSensor:
    """ PMW3389 pins: RST GND MT SS SCK MOSI MISO VIN

      RST:  -
      GND:  black
      MT:   -
      SS:   white
      SCK:  blue
      MOSI: green
      MISO: yellow
      VSYS: red
    """
    _SCK = board.GP18
    _MISO = board.GP16
    _MOSI = board.GP19
    _CS = board.GP17  # == SS
    _MT_PIN = board.A0
    _TARGET_CPI = 800

    def __init__(self):
        self._sensor = right_pmw3389.PMW3389(sck=self._SCK, mosi=self._MOSI, miso=self._MISO, cs=self._CS)
        self._mt_pin = DigitalInOut(board.A0)
        self._mt_pin.direction = Direction.INPUT

    def init_sensor(self) -> None:
        # Initialize sensor. You can specify CPI as an argument. Default CPI is 800.
        if self._sensor.begin():
            print("sensor ready")
        else:
            print("firmware upload failed")

        # Setting and getting CPI values
        self._sensor.set_CPI(self._TARGET_CPI)
        while True:
            cpi = self._sensor.get_CPI()
            print(f'cpi = {cpi}')
            if cpi == self._TARGET_CPI:
                break
            time.sleep(0.1)

    def update_sensor(self) -> tuple[int, int] | None:
        data = self._sensor.read_burst()

        # Limit values if needed
        dx = self._constrain(self._delta(data["dx"]), -127, 127)
        dy = self._constrain(self._delta(data["dy"]), -127, 127)

        # uncomment if mt_pin isn't used
        # if data["isOnSurface"] == True and data["isMotion"] and mt_pin.value == True:
        if self._mt_pin.value == 0 and (dy != 0 or dy != 0):
            #print(f'move ({dx}, {dy})')
            #mouse_device.move(-dy, -dx)  # !! swap values - only for testing !!
            return -dy, -dx

        return None

    @staticmethod
    def _constrain(val: int, min_val: int, max_val: int) -> int:
        return min(max_val, max(min_val, val))

    @staticmethod
    def _delta(value: int) -> int:
        """ Convert 16-bit unsigned value into a signed value
        """
        # Negative if MSB is 1
        if value & 0x8000:
            return -(~value & 0x7FFF)

        return value & 0x7FFF


class RightKeyboardSide:
    _BUTTON_MAP = {
        RIGHT_INDEX2_UP: board.GP2,  # blue
        RIGHT_INDEX_UP: board.GP3,  # yellow
        RIGHT_INDEX_DOWN: board.GP0,  # red  (orig GP4)
        RIGHT_INDEX2_DOWN: board.GP5,  # green
        RIGHT_MIDDLE_UP: board.GP10,  # blue
        RIGHT_MIDDLE_DOWN: board.GP11,  # yellow
        RIGHT_RING_UP: board.GP12,  # red
        RIGHT_RING_DOWN: board.GP13,  # blue
        RIGHT_PINKY_UP: board.GP14,  # red
        RIGHT_PINKY_DOWN: board.GP15,  # yellow
        RIGHT_THUMB_UP: board.GP21,  # red
        RIGHT_THUMB_DOWN: board.GP20,  # yellow
    }

    def __init__(self):
        self._trackball_sensor = TrackballSensor()
        self._uart = RightUart(tx=RIGHT_TX, rx=RIGHT_RX)
        self._buttons = [Button(pkey_serial=pkey_serial, gp_pin=gp_pin) for pkey_serial, gp_pin in self._BUTTON_MAP.items()]
        self._kbd_half = KeyboardHalf(key_groups=[KeyGroup(group_data)
                                                  for group_data in RIGHT_KEY_GROUPS])
    def init(self) -> None:
        print('init')
        self._trackball_sensor.init_sensor()
        print('init uart...')
        self._uart.wait_for_start()

    def main_loop(self) -> None:
        while True:
            t = time.monotonic() * 1000  # todo: before or after get_pressed_keys()?

            mouse_dx_dy = self._trackball_sensor.update_sensor()
            if mouse_dx_dy is not None:
                self._uart.write_mouse_move(*mouse_dx_dy)

            pressed_pkeys = self._get_pressed_pkeys()
            vkey_events = list(self._kbd_half.update(time=t, cur_pressed_pkeys=pressed_pkeys))
            if len(vkey_events) > 0:
                self._uart.write_vkey_events(vkey_events)

            time.sleep(0.01)

    def _get_pressed_pkeys(self) -> set[PhysicalKeySerial]:
        return {button.pkey_serial
                for button in self._buttons
                if button.is_pressed()}

    # def print_keyboard_info(self, virt_keyboard: VirtualKeyboard) -> None:
    #     for vkey in virt_keyboard.iter_all_virtual_keys():
    #         print(f'{vkey.serial} ({str(type(vkey))}): ')
    #         for pkey in vkey.physical_keys:
    #             print(f'- {pkey.serial} ({id(pkey)}) ({str(type(pkey))})')


if __name__ == '__main__':
    main()

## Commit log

2026-03-07 fix test: KeyboardCreatorTest.test_with_real_layout() # problem was, that Q is a tap/hold key
    [test_keyboardcreator.py]
2026-03-13 add some pictures and some STL files
    [finger-double-ball-holder1.stl, finger-double-ball-holder2.stl, skeleton-with-sphere.stl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]
2026-03-14 add stl files
    [circle-base-cover.stl, circle-base-plate.stl, controller-holder-plate.stl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]
2026-03-21 new index finger caps: bended big cap - move LameKeyCapGridCreator: klp_lame_saddle.py -> main_grid_caps.py
2026-03-22 case: add x correction value for switch pair holders
2026-03-26 reduce length of double ball join for fingers and extend screw cylinder by 1mm for better wing movement
2026-03-30 - remove unused KeyGroupSerial - move side specific part of uart -> mainleft.py + mainright.py
2026-04-03 fix layer problem - make SimpleLayerTest green
    [left_virtualkeyboard.py]
2026-04-10 firmware: simplify VirtualKeyboard + fix it
    [left_keyboardcreator.py, left_virtualkeyboard.py, test_virtualkeyboard.py]
2026-04-10 firmware: use automatically tap (no hold variant) for ModKeys with mouse button reactions
2026-04-12 firmware: 1st improvement of roller encoder
2026-04-13 firmware: improve rotary encoder
